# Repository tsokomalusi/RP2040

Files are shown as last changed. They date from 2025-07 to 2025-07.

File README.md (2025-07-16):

# Custom PCB Design Raspberry Pi Pico (RP2040)
I designed a custom PCB based on the RP2040 microcontroller using KiCad 9.0,
following the official RP2040 hardware design guidelines.This version includes
several enhancements to improve usability and protection:
- ESD protection on the USB interface
- SWD header for debugging
- Dedicated Boot and Reset push-buttons

## Schematic
Schematic

## PCB Layout
PCB_Layout

## 3D Model
3D_Model

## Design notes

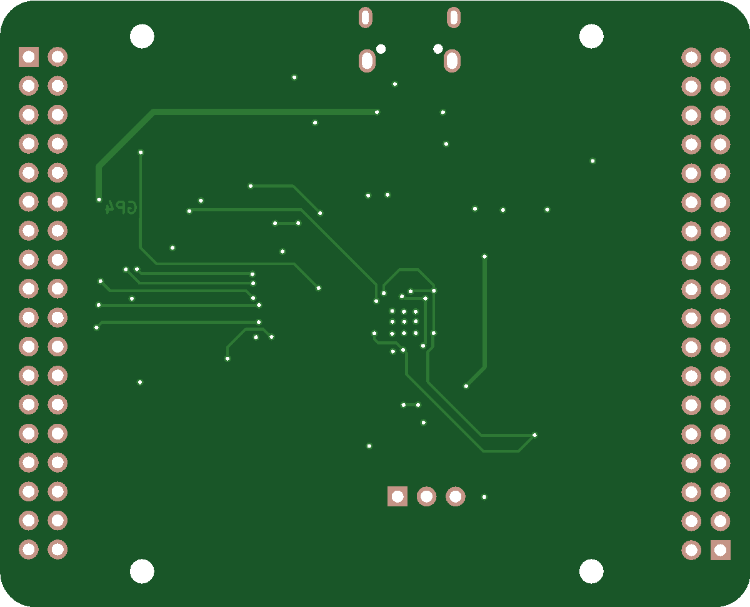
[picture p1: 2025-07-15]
images/simulation_image_bottom (1).png

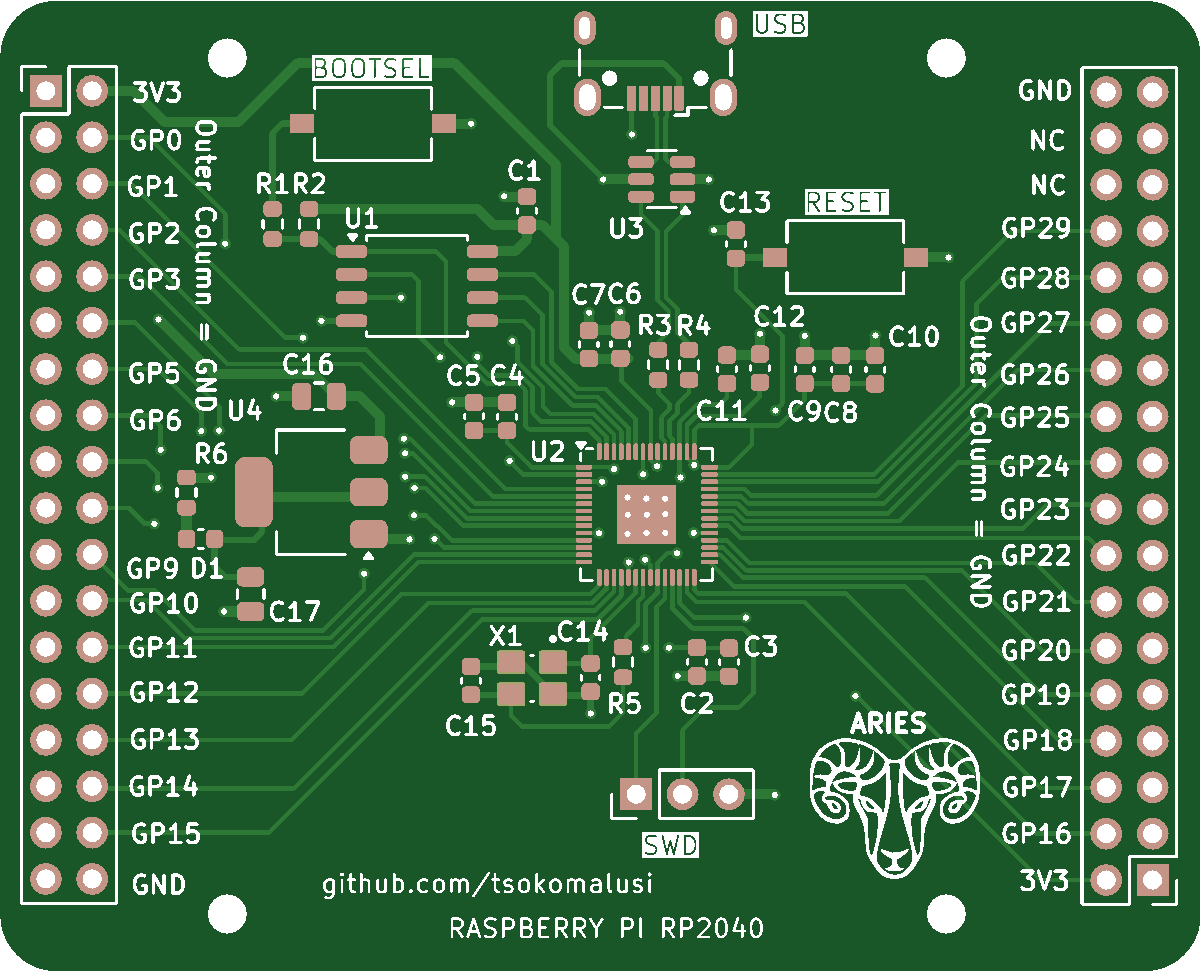
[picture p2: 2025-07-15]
images/simulation_image_top (1).png

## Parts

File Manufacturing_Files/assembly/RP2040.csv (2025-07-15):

Reference | Qty | Value | DNP | Exclude from BOM | Exclude from Board | Footprint | Datasheet
C1,C2,C3,C4,C5,C6,C7,C8,C9,C10,C13 | 11 | 100n |  |  |  | Capacitor_SMD:C_0603_1608Metric | ~
C11,C12 | 2 | 1u |  |  |  | Capacitor_SMD:C_0603_1608Metric | ~
C14,C15 | 2 | 10p |  |  |  | Capacitor_SMD:C_0603_1608Metric | ~
C16,C17 | 2 | 10u |  |  |  | Capacitor_SMD:C_0805_2012Metric | ~
D1 | 1 | GREEN |  |  |  | Capacitor_SMD:C_0603_1608Metric | ~
H1,H2,H3,H4 | 4 | MountingHole |  | Excluded from BOM |  | MountingHole:MountingHole_2.1mm | ~
J1 | 1 | GPIO_CONN_B |  |  |  | Connector_PinHeader_2.54mm:PinHeader_2x18_P2.54mm_Vertical | ~
J2 | 1 | GPIO Conn_A |  |  |  | Connector_PinHeader_2.54mm:PinHeader_2x18_P2.54mm_Vertical | ~
J3 | 1 | SWD |  |  |  | Connector_PinHeader_2.54mm:PinHeader_1x03_P2.54mm_Vertical | ~
J4 | 1 | USB_B_Micro |  |  |  | Connector_USB:USB_Micro-B_Wuerth_629105150521 | ~
R1,R5 | 2 | 1K |  |  |  | Resistor_SMD:R_0603_1608Metric | ~
R2 | 1 | DNF | DNP |  |  | Resistor_SMD:R_0603_1608Metric | ~
R3,R4 | 2 | 27R |  |  |  | Resistor_SMD:R_0603_1608Metric | ~
R6 | 1 | 1K5 |  |  |  | Resistor_SMD:R_0603_1608Metric | ~
SW1 | 1 | BOOTSEL |  |  |  | Button_Switch_SMD:SW_Tactile_SPST_NO_Straight_CK_PTS636Sx25SMTRLFS | ~
SW2 | 1 | RESET |  |  |  | Button_Switch_SMD:SW_Tactile_SPST_NO_Straight_CK_PTS636Sx25SMTRLFS | ~
U1 | 1 | W25Q128JVS |  |  |  | Package_SO:SOIC-8_5.3x5.3mm_P1.27mm | https://www.winbond.com/resource-files/w25q128jv_dtr%20revc%2003272018%20plus.pdf
U2 | 1 | RP2040 |  |  |  | Package_DFN_QFN:QFN-56-1EP_7x7mm_P0.4mm_EP3.2x3.2mm | https://datasheets.raspberrypi.com/rp2040/rp2040-datasheet.pdf
U3 | 1 | USBLC6-2SC6 |  |  |  | Package_TO_SOT_SMD:SOT-23-6 | https://www.st.com/resource/en/datasheet/usblc6-2.pdf
U4 | 1 | AMS1117-3.3 |  |  |  | Package_TO_SOT_SMD:SOT-223-3_TabPin2 | http://www.advanced-monolithic.com/pdf/ds1117.pdf
X1 | 1 | 12MHz |  |  |  | Crystal:XTAL_ABM8-272-T3 | ~

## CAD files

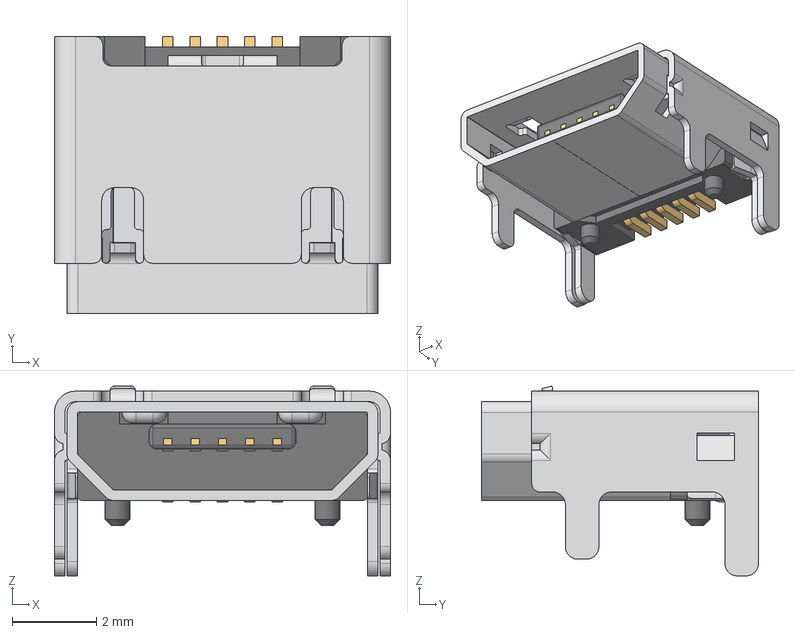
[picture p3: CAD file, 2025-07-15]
step files/Download_STP_629105150521_rev1.stp
8.00 x 6.60 x 4.52 mm
629105150521_Housing
629105150521_Pin1 x 4
629105150521_Pin2
629105150521_Shielding2
629105150521_Shielding

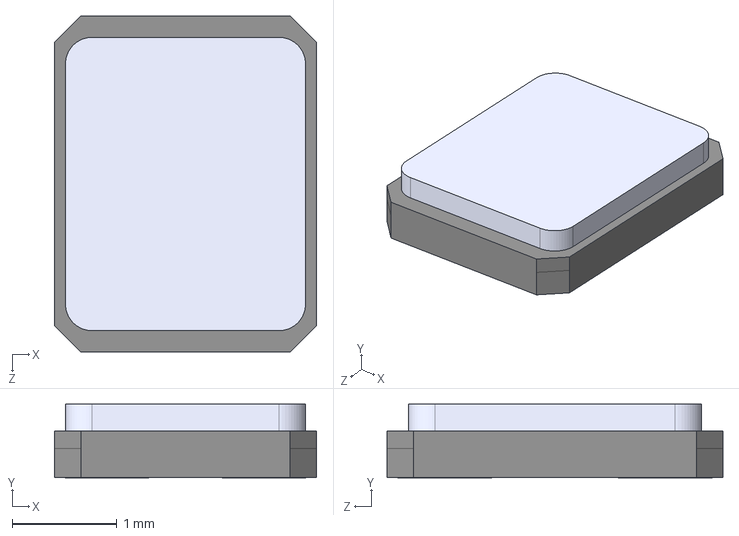
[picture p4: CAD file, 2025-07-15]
step files/ABM8-272-T3.step
2.50 x 0.7 x 3.20 mm

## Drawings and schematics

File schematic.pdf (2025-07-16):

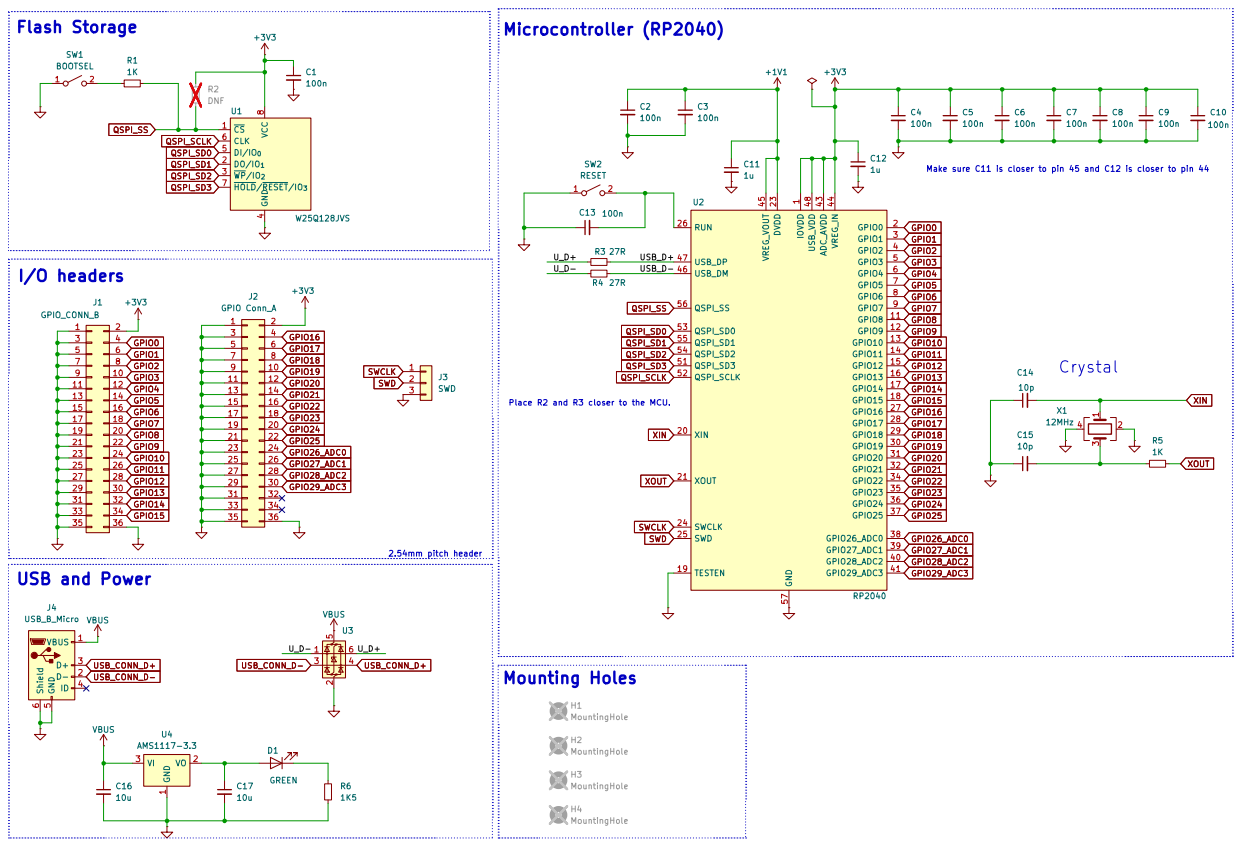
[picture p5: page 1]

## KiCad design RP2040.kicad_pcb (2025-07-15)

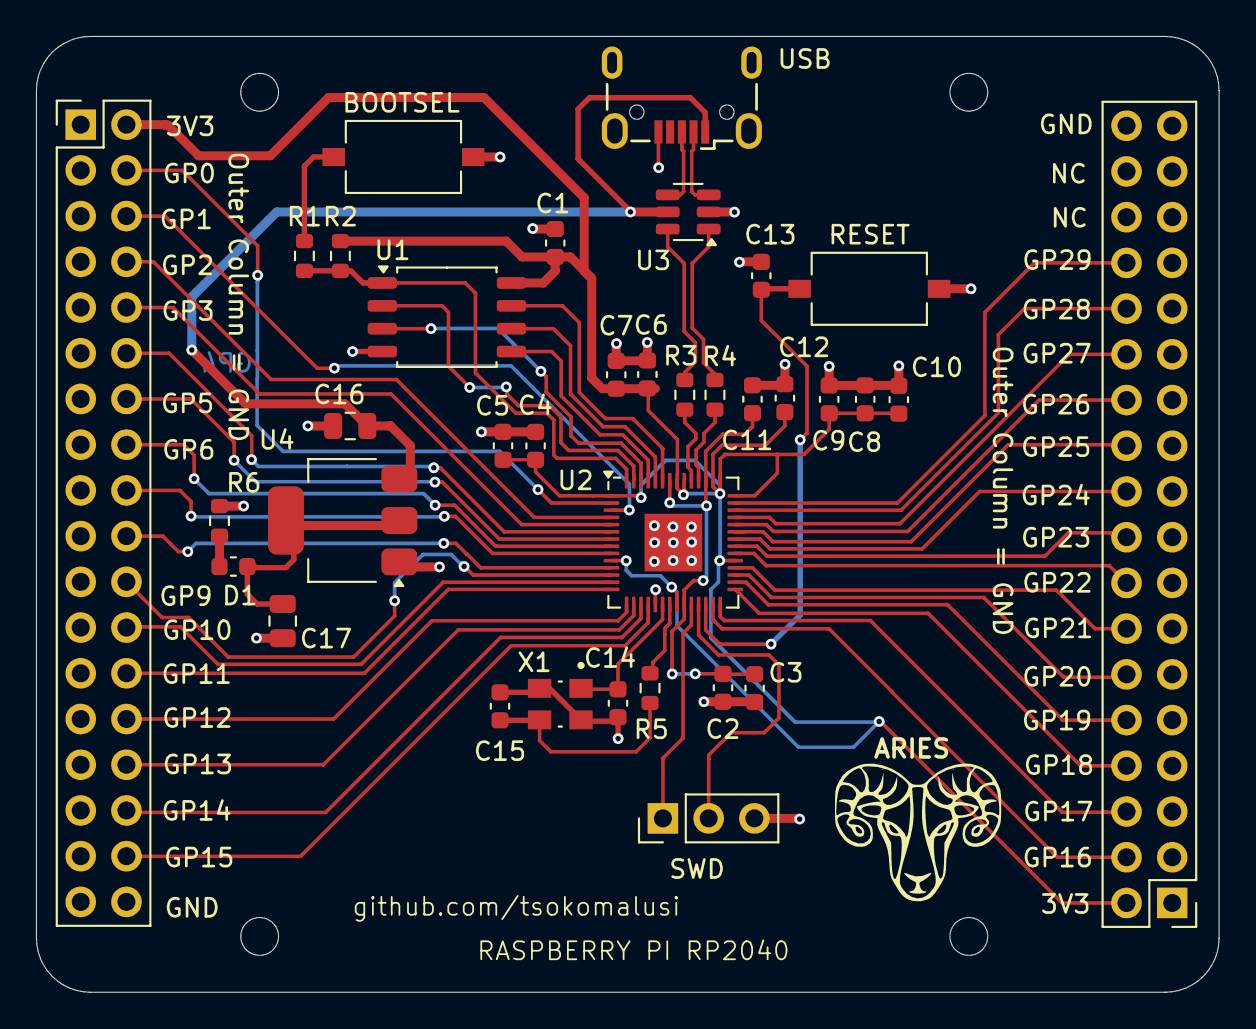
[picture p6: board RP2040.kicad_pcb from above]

Board: 4 copper layers, 65.7 x 53.1 mm, 39 parts (0 on the bottom side), 55 nets.

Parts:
BOOTSEL: BOOTSEL; SW_Tactile_SPST_NO_Straight_CK_PTS636Sx25SMTRLFS
C1, C2, C3, C4, C5, C6, C7, C8, C9, C10, C13: 100n; C_0603_1608Metric
C11, C12: 1u; C_0603_1608Metric
C14, C15: 10p; C_0603_1608Metric
C16, C17: 10u; C_0805_2012Metric
D1: GREEN; C_0603_1608Metric
H1, H2, H3, H4: MountingHole; MountingHole_2.1mm
J1, J2: Conn_02x18_Odd_Even; PinHeader_2x18_P2.54mm_Vertical
R1, R5: 1K; R_0603_1608Metric
R2: DNF; R_0603_1608Metric
R3, R4: 27R; R_0603_1608Metric
R6: 1K5; R_0603_1608Metric
RESET: RESET; SW_Tactile_SPST_NO_Straight_CK_PTS636Sx25SMTRLFS
SWD: Conn_01x03; PinHeader_1x03_P2.54mm_Vertical
U1: W25Q128JVS; SOIC-8_5.3x5.3mm_P1.27mm
U2: RP2040; QFN-56-1EP_7x7mm_P0.4mm_EP3.2x3.2mm
U3: USBLC6-2SC6; SOT-23-6
U4: AMS1117-3.3; SOT-223-3_TabPin2
USB: USB_B_Micro; USB_Micro-B_Wuerth_629105150521
X1: 12MHz; XTAL_ABM8-272-T3

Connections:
+1V1: C2.1, C3.1, C11.1, U2.23 (DVDD), U2.45 (VREG_VOUT), U2.50 (DVDD)
+3V3: C1.1, C4.1, C5.1, C6.1, C7.1, C8.1, C9.1, C10.1, C12.1, J1.2, J2.2, R2.1, U1.8 (VCC), U2.1 (IOVDD), U2.10 (IOVDD), U2.22 (IOVDD), U2.33 (IOVDD), U2.42 (IOVDD), U2.43 (ADC_AVDD), U2.44 (VREG_IN), U2.48 (USB_VDD), U2.49 (IOVDD)
/USB_D+: R3.2, U2.47 (USB_DP)
/USB_D-: R4.2, U2.46 (USB_DM)
/U_D+: R3.1, U3.6 (I/O1)
/U_D-: R4.1, U3.1 (I/O1)
GND: BOOTSEL.1 (A), C1.2, C2.2, C3.2, C4.2, C5.2, C6.2, C7.2, C8.2, C9.2, C10.2, C11.2, C12.2, C13.1, C14.1, C15.1, C16.2, C17.2, J1.1, J1.3, J1.5, J1.7, J1.9, J1.11, J1.13, J1.15, J1.17, J1.19, J1.21, J1.23, J1.25, J1.27, J1.29, J1.31, J1.33, J1.35, J1.36, J2.1, J2.3, J2.5, J2.7, J2.9, J2.11, J2.13, J2.15, J2.17, J2.19, J2.21, J2.23, J2.25, J2.27, J2.29, J2.31, J2.33, J2.35, J2.36, R6.2, RESET.1 (A), SWD.3, U1.4 (GND), U2.19 (TESTEN), U2.57 (GND), U3.2 (GND), U4.1 (GND), USB.5 (GND), USB.6 (Shield), X1.2, X1.4
GPIO0: J1.4, U2.2 (GPIO0)
GPIO1: J1.6, U2.3 (GPIO1)
GPIO2: J1.8, U2.4 (GPIO2)
GPIO3: J1.10, U2.5 (GPIO3)
GPIO4: J1.12, U2.6 (GPIO4)
GPIO5: J1.14, U2.7 (GPIO5)
GPIO6: J1.16, U2.8 (GPIO6)
GPIO7: J1.18, U2.9 (GPIO7)
GPIO8: J1.20, U2.11 (GPIO8)
GPIO9: J1.22, U2.12 (GPIO9)
GPIO10: J1.24, U2.13 (GPIO10)
GPIO11: J1.26, U2.14 (GPIO11)
GPIO12: J1.28, U2.15 (GPIO12)
GPIO13: J1.30, U2.16 (GPIO13)
GPIO14: J1.32, U2.17 (GPIO14)
GPIO15: J1.34, U2.18 (GPIO15)
GPIO16: J2.4, U2.27 (GPIO16)
GPIO17: J2.6, U2.28 (GPIO17)
GPIO18: J2.8, U2.29 (GPIO18)
GPIO19: J2.10, U2.30 (GPIO19)
GPIO20: J2.12, U2.31 (GPIO20)
GPIO21: J2.14, U2.32 (GPIO21)
GPIO22: J2.16, U2.34 (GPIO22)
GPIO23: J2.18, U2.35 (GPIO23)
GPIO24: J2.20, U2.36 (GPIO24)
GPIO25: J2.22, U2.37 (GPIO25)
GPIO26_ADC0: J2.24, U2.38 (GPIO26_ADC0)
GPIO27_ADC1: J2.26, U2.39 (GPIO27_ADC1)
GPIO28_ADC2: J2.28, U2.40 (GPIO28_ADC2)
GPIO29_ADC3: J2.30, U2.41 (GPIO29_ADC3)
unnamed: C15.2, R5.1, X1.3
unnamed: C17.1, D1.2 (A), U4.2 (VO)
unnamed: D1.1 (K), R6.1
unnamed: BOOTSEL.2 (B), R1.1
unnamed: C13.2, RESET.2 (B), U2.26 (RUN)
QSPI_SCLK: U1.6 (CLK), U2.52 (QSPI_SCLK)
QSPI_SD0: U1.5 (DI/IO_{0}), U2.53 (QSPI_SD0)
QSPI_SD1: U1.2 (DO/IO_{1}), U2.55 (QSPI_SD1)
QSPI_SD2: U1.3 (~WP/IO_{2}), U2.54 (QSPI_SD2)
QSPI_SD3: U1.7 (~HOLD/~RESET/IO_{3}), U2.51 (QSPI_SD3)
QSPI_SS: R1.2, R2.2, U1.1 (~CS), U2.56 (QSPI_SS)
SWCLK: SWD.1, U2.24 (SWCLK)
SWD: SWD.2, U2.25 (SWD)
USB_CONN_D+: U3.4 (I/O2), USB.3 (D+)
USB_CONN_D-: U3.3 (I/O2), USB.2 (D-)
VBUS: C16.1, U3.5 (VBUS), U4.3 (VI), USB.1 (VBUS)
XIN: C14.2, U2.20 (XIN), X1.1
XOUT: R5.2, U2.21 (XOUT)

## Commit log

2025-07-15 uploading all files
    [ABM8-272-T3.step, Download_STP_629105150521_rev1.stp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]
2025-07-16 adding the schematic
